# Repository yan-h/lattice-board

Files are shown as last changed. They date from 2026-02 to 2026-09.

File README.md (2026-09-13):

MIDI controller using the Wicki-Hayden layout. Heavily inspired by [Hexboard](https://shapingthesilence.com/tech/hexboard-midi-controller/), [Striso](https://www.striso.org) and [Lumatone](https://www.lumatone.io).
- 123 keys with individual LED lighting
  - 5 octaves
  - Fifthspan of 25 - i.e. each octave contains 25 notes, spanning an unbroken segment of the chain of fifths
    - Size of fifth is adjustable in firmware, providing easy access to all temperaments based on pure octaves and a chain of equal-sized perfect fifths.
- Very portable
  - 21x22x2.5cm
  - Similar in size to a small tablet, and much lighter than one.
- Tiny keys (17mm) for my tiny hands (and easier microtonal chords)
- No velocity sensitivity (or any other form of MIDI expression). This simplifies the engineering constraints by a lot, and let me design it as a very weirdly shaped mechanical keyboard.

Engineering overview
- Case and keycaps 3D-printed in PETG (Bambu Lab translucent PETG and black PETG-HF)
  - [3D models](https://cad.onshape.com/documents?nodeId=e71b068a262a341693bc0b63&resourceType=folder) made using Onshape. 
  - Printed using a Bambu Lab P1S. Keycaps were printed with the Darkmoon Satin build plate, to obtain a texture finer than a textured PEI plate, but coarser than a smooth plate.
- TTC Frozen Silent V2 Keyswitches - fully transparent, light condenser, silent.
- PCB designed in KiCad 9, manufactured with JLCPCB
- Firmware in Rust with [Embassy](https://embassy.dev/). Heavily vibecoded.
  - See [firmware/README.md](firmware/README.md) for build and flashing instructions, and the serial configuration dashboard.

Future work: [7-octave, fifthspan-50 redesign findings](docs/7x50-redesign-notes.md).




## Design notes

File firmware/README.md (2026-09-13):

# LatticeBoard firmware

Rust firmware for the RP2040, built on [Embassy](https://embassy.dev/). The board enumerates as a composite USB device with two interfaces:

- **USB-MIDI** — the actual instrument output
- **USB-CDC serial** — live logs and an interactive configuration dashboard (see below)

## Workspace layout

- `core/` — hardware-independent layout and pitch math (`layout.rs`, `pitch.rs`)
- `controller/` — the firmware binary: key scanning, LEDs, MIDI/MPE, tuning, USB

## Hardware layouts (cargo features)

Two mutually exclusive features in `controller/Cargo.toml` select the target hardware:

| Feature | Hardware | LEDs | LED data pin |
|---|---|---|---|
| `layout-prototype` (**default**) | small test board | 20 | GPIO 29 |
| `layout-5x25` | the full 123-key board | 125 | GPIO 3 |

The default is the prototype, so **building the real keyboard requires overriding the default feature** (see below).

## Prerequisites

- [rustup](https://rustup.rs) — `rust-toolchain.toml` pins Rust 1.90 and the `thumbv6m-none-eabi` target; both are installed automatically the first time you run cargo in this directory.
- [`elf2uf2-rs`](https://crates.io/crates/elf2uf2-rs) — used by the cargo runner to flash: `cargo install elf2uf2-rs`

## Build

```sh
cd firmware
cargo build --release --no-default-features --features layout-5x25   # full board
cargo build --release                                                # prototype
```

## Flash

Flashing is wired into `cargo run` via `.cargo/config.toml` — no debug probe needed, just USB:

```sh
cargo run --release --no-default-features --features layout-5x25
```

The runner script:

1. Sets the board's CDC serial port (`/dev/tty.usbmodem*`) to 1200 baud. The firmware treats a 1200-baud line coding as a "reboot into the UF2 bootloader" signal (`check_for_reset` in `controller/src/usb.rs`).
2. Waits 3 seconds for the `RPI-RP2` mass-storage bootloader to mount.
3. Runs `elf2uf2-rs -d`, which converts the ELF to UF2 and copies it to the board.

**Recovery / first flash:** if the board isn't running this firmware (so the 1200-baud trick doesn't work), hold the RP2040's BOOTSEL button while plugging in USB, then run the same `cargo run` command — the `stty` step fails harmlessly and `elf2uf2-rs` deploys as usual.

The runner script is macOS-specific (`stty -f /dev/tty.usbmodem*`); on Linux adjust to `stty -F /dev/ttyACM*`.

## Serial dashboard

Connect any terminal emulator to the CDC port (any baud rate except 1200, which triggers the bootloader reset):

```sh
screen /dev/tty.usbmodem*
```

The port starts in **log mode**, streaming `log`/defmt-style output. Press `d` to toggle the live **dashboard**, which shows brightness, hue, tuning mode, fifth size, MPE pitch-bend range, held keys, and remote MIDI voices, plus a key legend:

| Keys | Action |
|---|---|
| `[` / `]` | select previous/next of the 12 note-color anchors |
| `r`/`R`, `g`/`G`, `b`/`B` | adjust the selected anchor's RGB channels ±5 |
| `H` / `h` | shift hue offset ±1° |
| `L` / `l` | brightness ±0.05 |
| `+` / `-` | brightness ±0.02 (fine) |
| `t` | toggle tuning mode: `Standard` (12-TET MIDI notes) ↔ `Fifths` (MPE, adjustable fifth) |
| `(` / `)` | fifth size ±1 cent (clamped to 600–800¢) |
| `{` / `}` | fifth size ±0.1 cent |
| `d` | back to log mode |

Settings are in-memory only — they reset to the defaults in `controller/src/leds.rs` and `controller/src/tuning.rs` on power cycle. To persist a tweak, change the defaults there and reflash.

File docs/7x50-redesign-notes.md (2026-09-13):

# Larger keyboard: 7 octaves × fifthspan 50

Feasibility assessment saved September 12, 2026, against commit
`ee68e6a654281d804561bd37a6d07c5cd6d7d9c4`.

Status: exploratory findings only. No PCB, schematic, firmware, or mechanical
design changes have been made for this revision. The user is considering returning
to this project later; this document is the starting context for that work.

## Intent and assessment

Expand the existing Wicki-Hayden mechanical-switch MIDI keyboard from 5 octaves
and fifthspan 25 to 7 octaves and fifthspan 50. “50 notes per octave” is assumed to
mean 50 consecutive positions on the chain of fifths, following the existing
README, rather than necessarily 50 equal divisions of the octave.

This appears feasible as a medium-sized hardware revision. Existing key circuitry,
footprints, routing templates, and the RP2040 controller are useful starting
points. Expect several focused design/review sessions for a first reviewable
fabrication candidate, then manufacturing and physical bring-up, with allowance
for another PCB revision. This is a preliminary effort estimate, not a validated
schedule or a guarantee that the first manufactured board will work.

| Item | Existing board | Candidate larger board |
|---|---|---|
| Key positions | 125 nominal; 123 populated | About 350, depending on controller space |
| Scan matrix | 10 rows × 13 columns | Potentially 14 rows × 25 columns |
| Column shift registers | Two 74HC595s | Four 74HC595s, with spare outputs |
| Controller | RP2040-Zero | Likely reusable |
| Size | PCB outline about 209 × 197 mm; case about 21 × 22 cm | Roughly 40 × 28 cm at existing spacing; unverified estimate |

The proposed matrix dimensions describe electrical scanning, not a finalized
physical key arrangement. Exact fifthspan boundaries and the change from an odd
to an even fifthspan need to be worked out when generating the geometry.

## Verified baseline

- Main design: [pcb/5x25](../pcb/5x25/), KiCad 9 schematic and PCB.
- Four copper layers; the PCB includes a 5 V inner-layer zone and ground zones.
- PCB footprint inventory: 123 switches, 123 LEDs, 124 diodes, 125 capacitors,
  two 74HC595s, one RP2040-Zero, one resistor, and nine mounting holes.
- Two musical key positions are omitted for the controller.
- The controller currently uses ten row inputs, three shift-register control
  pins, and one LED data pin. Six footprint GPIO pins are unconnected.
- KiCad DRC with schematic parity checking reported zero unconnected items,
  zero schematic parity issues, and four warnings. All four warnings were
  capacitor footprints differing from their library copies: C14, C63, C88, C113.
  This establishes a useful baseline; it does not verify electrical performance.

Reproduce the baseline check from the repository root:

```sh
kicad-cli pcb drc --format json --schematic-parity \
  -o /tmp/lattice-5x25-drc.json pcb/5x25/5x25.kicad_pcb
```

On the inspected Mac, the CLI was at
`/Applications/KiCad/KiCad.app/Contents/MacOS/kicad-cli`.

## PCB and mechanical work

1. **Generate the geometry from parameters.**
   [lattice_plugins.py](../pcb/5x25/lattice_plugins.py) already clones local
   component placement and trace templates, but hardcodes 125 keys, groups of 25,
   five groups, and specific row/column/LED connections. It is a useful source of
   reusable patterns, not a complete arbitrary-size board generator. Prefer one
   authoritative layout definition that generates PCB placement and firmware
   mappings, with explicit treatment of edge keys and omitted positions.
2. **Expand the matrix and validate scanning.**
   A candidate 14×25 matrix needs 14 input pins plus three shift-register control
   pins and one LED pin: 18 GPIOs. This fits the RP2040-Zero's 20 edge GPIOs.
   Four cascaded 8-bit 595s provide enough column outputs. Pin assignment,
   initialization, scan timing, and long interconnect behavior still need review.
3. **Establish an LED power budget.**
   At comparable lighting settings, LED load scales to approximately 2.8 times
   the current board. Measure or verify the actual LED current, decide maximum
   brightness, then design the supply path, copper distribution, decoupling,
   input protection, and logic-level interface accordingly. USB-only power versus
   a separate supply remains undecided.
4. **Update the enclosure and mounting scheme.**
   The much wider PCB needs appropriate mechanical support. Compare a single
   PCB with connected sections if fabrication or enclosure constraints justify
   that complexity. Local mechanical files in [models](../models/) are STEP/3MF
   exports; the README links the original Onshape models. The editable Onshape
   design was not inspected in this assessment.

Hardware references checked during the assessment:
[Waveshare RP2040-Zero documentation](https://www.waveshare.com/wiki/RP2040-Zero)
and [TI SN74HC595 documentation](https://www.ti.com/product/SN74HC595).

## Firmware findings to carry forward

- **LED indices must be widened.**
  [layout_5x25.rs](../firmware/controller/src/layouts/layout_5x25.rs) uses `u8`
  entries and reserves `255` for `NO_LED`; indices for 350 LEDs cannot fit.
  The generic reverse-lookup helper in
  [core/layout.rs](../firmware/core/src/layout.rs) also accepts `u8` entries.
  Use a wider representation and an unambiguous missing-entry value.
- **Unify LED counts.** The layout declares 123 LEDs, while
  [leds.rs](../firmware/controller/src/leds.rs) sends a 125-LED buffer.
- **Add a layout and update row pin assignments.** The scanner in
  [keys/shift_reg.rs](../firmware/controller/src/keys/shift_reg.rs) loops over
  layout constants, but the current row-pin macro names exactly ten pins.
  RAM for a few hundred keys and LEDs appears modest; actual scan latency and
  CPU load have not been benchmarked.
- **Review LED refresh cost.** At an assumed 800 kHz, transmitting 350 RGB LEDs
  takes about 10.5 ms before reset time, while the task requests a 2 ms tick.
  Lighting also repeatedly searches the board for pitches per active voice.
  Choose a realistic refresh rate and consider cached or change-driven updates.
- **Review event bursts and held-key capacities.** The scanner drops events if
  its 32-entry MIDI queue is full, potentially losing note-offs. Local held-key
  visualization has a 16-entry capacity; other voice/highlight collections have
  32-entry limits. More total keys do not inherently require more polyphony, but
  the intended simultaneous-key behavior and debounce should be checked.
- **Preserve the distinction between MIDI modes.** In the inspected
  [tuning.rs](../firmware/controller/src/tuning.rs), `Fifths` is the default and
  encodes octave/fifth offsets as channel/note numbers, clamped to 16 channels
  and 128 notes. Validate the new layout center and all edge coordinates to avoid
  clamping aliases. `Standard` with a non-700-cent fifth uses the MPE allocator,
  which has 15 note channels; that limit is simultaneous bent voices, not total
  keyboard keys. Do not assume the README fully describes current behavior.

## Suggested restart point

First generate a reviewable 7×50 physical key layout and board outline, preserving
the existing switch/keycap geometry. Confirm the exact fifthspan, musical range,
controller location, hand reach, and desk footprint before detailed routing.

Then settle power and single-board versus sectional construction; produce the
schematic, placement, routing, mounting, and firmware mappings from the agreed
layout. Verify mapping uniqueness and coverage, DRC/ERC and schematic parity,
firmware builds, and power/mechanical assumptions before preparing fabrication
files. Physical bring-up should exercise every key and LED, simultaneous presses,
release-event reliability, scan latency, and voltage drop at maximum permitted
brightness.

No budget, power architecture, sectional construction, or exact outline has been
approved yet. Do not treat the candidate dimensions or scan matrix as final design
requirements.

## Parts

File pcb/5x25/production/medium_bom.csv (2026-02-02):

Designator | Footprint | Quantity | Value | LCSC Part #
C10, C100, C101, C102, C103, C104, C105, C106, C107, C108, C109, C11, C110, C111, C112, C113, C114, C115, C116, C117, C118, C119, C12, C120, C121, C122, C123, C124, C125, C14, C15, C16, C17, C18, C19, C2, C20, C21, C22, C23, C24, C25, C26, C27, C28, C29, C3, C30, C31, C32, C33, C34, C35, C36, C37, C38, C39, C4, C40, C41, C42, C43, C44, C45, C46, C47, C48, C49, C5, C50, C51, C52, C53, C54, C55, C56, C57, C58, C59, C6, C60, C61, C62, C63, C64, C65, C66, C67, C68, C69, C7, C70, C71, C72, C73, C74, C75, C76, C77, C78, C79, C8, C80, C81, C82, C83, C84, C85, C86, C87, C88, C89, C9, C90, C900, C901, C91, C92, C93, C94, C95, C96, C97, C98, C99 | 0603 | 125 | 100nF
D10, D100, D101, D102, D103, D104, D105, D106, D107, D108, D109, D11, D110, D111, D112, D113, D114, D115, D116, D117, D118, D119, D12, D120, D121, D122, D123, D124, D125, D14, D15, D16, D17, D18, D19, D2, D20, D21, D22, D23, D24, D25, D26, D27, D28, D29, D3, D30, D31, D32, D33, D34, D35, D36, D37, D38, D39, D4, D40, D41, D42, D43, D44, D45, D46, D47, D48, D49, D5, D50, D51, D52, D53, D54, D55, D56, D57, D58, D59, D6, D60, D61, D62, D63, D64, D65, D66, D67, D68, D69, D7, D70, D71, D72, D73, D74, D75, D76, D77, D78, D79, D8, D80, D81, D82, D83, D84, D85, D86, D87, D88, D89, D9, D90, D900, D91, D92, D93, D94, D95, D96, D97, D98, D99 | D_SOD-323F | 124 | 1N4148WS
LED10, LED100, LED101, LED102, LED103, LED104, LED105, LED106, LED107, LED108, LED109, LED11, LED110, LED111, LED112, LED113, LED114, LED115, LED116, LED117, LED118, LED119, LED12, LED120, LED121, LED122, LED123, LED124, LED125, LED14, LED15, LED16, LED17, LED18, LED19, LED2, LED20, LED21, LED22, LED23, LED24, LED25, LED26, LED27, LED28, LED29, LED3, LED30, LED31, LED32, LED33, LED34, LED35, LED36, LED37, LED38, LED39, LED4, LED40, LED41, LED42, LED43, LED44, LED45, LED46, LED47, LED48, LED49, LED5, LED50, LED51, LED52, LED53, LED54, LED55, LED56, LED57, LED58, LED59, LED6, LED60, LED61, LED62, LED63, LED64, LED65, LED66, LED67, LED68, LED69, LED7, LED70, LED71, LED72, LED73, LED74, LED75, LED76, LED77, LED78, LED79, LED8, LED80, LED81, LED82, LED83, LED84, LED85, LED86, LED87, LED88, LED89, LED9, LED90, LED91, LED92, LED93, LED94, LED95, LED96, LED97, LED98, LED99 | SK6803-MINI-E | 123 | SK6803-MINI-E
R1 | 0402 | 1 | 220R
RZ1 | RP2040-Zero | 1 | RP2040-Zero
SW10, SW100, SW101, SW102, SW103, SW104, SW105, SW106, SW107, SW108, SW109, SW11, SW110, SW111, SW112, SW113, SW114, SW115, SW116, SW117, SW118, SW119, SW12, SW120, SW121, SW122, SW123, SW124, SW125, SW14, SW15, SW16, SW17, SW18, SW19, SW2, SW20, SW21, SW22, SW23, SW24, SW25, SW26, SW27, SW28, SW29, SW3, SW30, SW31, SW32, SW33, SW34, SW35, SW36, SW37, SW38, SW39, SW4, SW40, SW41, SW42, SW43, SW44, SW45, SW46, SW47, SW48, SW49, SW5, SW50, SW51, SW52, SW53, SW54, SW55, SW56, SW57, SW58, SW59, SW6, SW60, SW61, SW62, SW63, SW64, SW65, SW66, SW67, SW68, SW69, SW7, SW70, SW71, SW72, SW73, SW74, SW75, SW76, SW77, SW78, SW79, SW8, SW80, SW81, SW82, SW83, SW84, SW85, SW86, SW87, SW88, SW89, SW9, SW90, SW91, SW92, SW93, SW94, SW95, SW96, SW97, SW98, SW99 | SW_MX_17 | 123 | MX_Switch
U1, U2 | TSSOP-16 | 2 | 74HC595

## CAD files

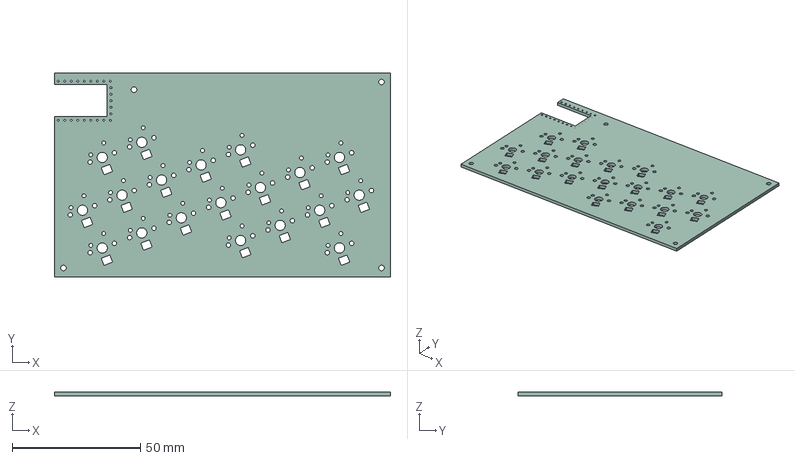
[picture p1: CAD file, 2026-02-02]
models/boards/prototype.step
131.0 x 79.5 x 1.51 mm

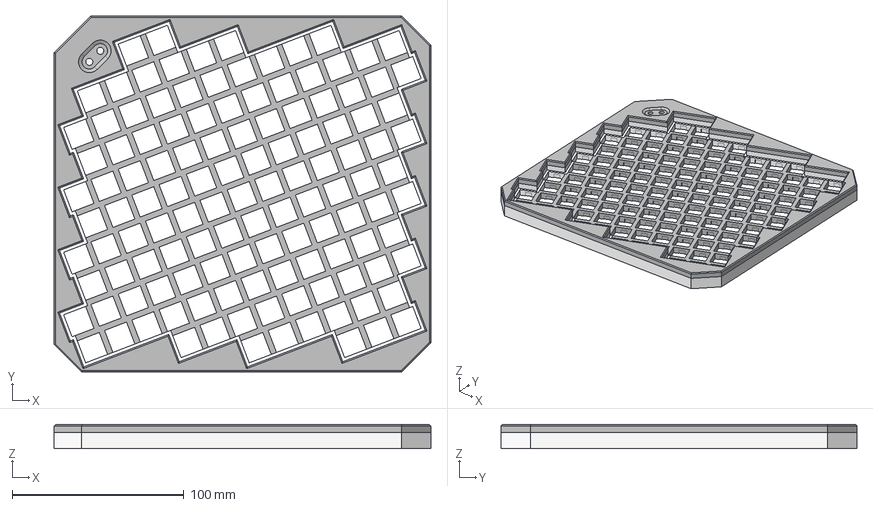
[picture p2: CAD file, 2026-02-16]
models/cases/5x25/top.step
219.4 x 207.4 x 14.0 mm

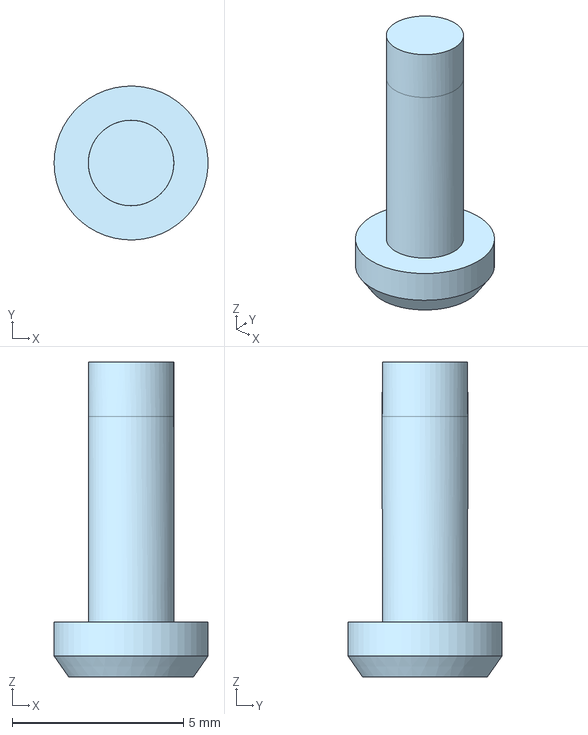
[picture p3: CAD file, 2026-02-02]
models/cases/prototype/button_rod.step
4.50 x 4.50 x 9.21 mm

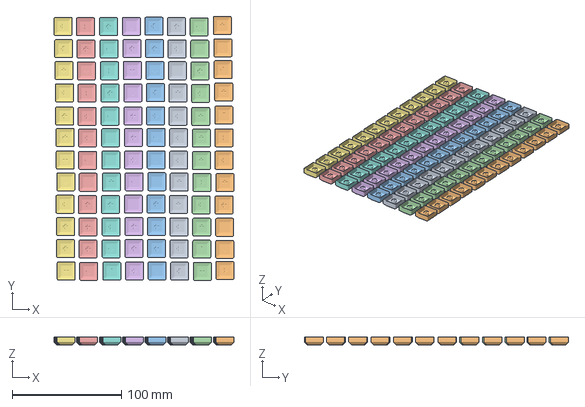
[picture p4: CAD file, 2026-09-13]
models/keycaps/17mm_keycaps.3mf
164.7 x 241.6 x 7.40 mm
key_a0.step x 48
key_a1.step x 48

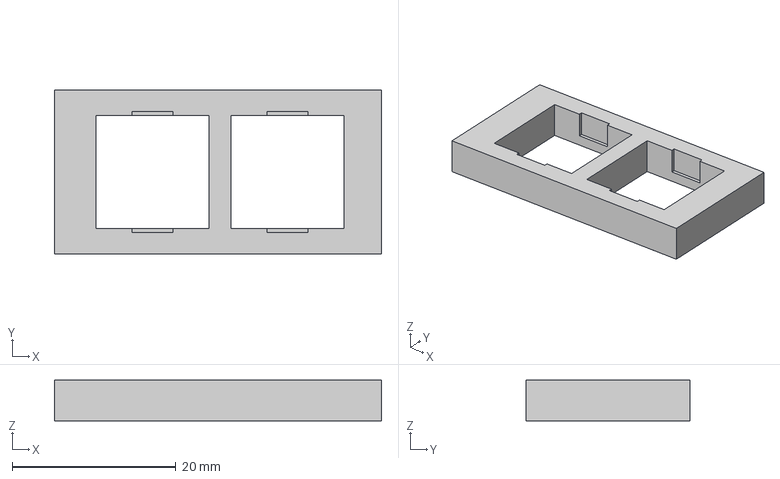
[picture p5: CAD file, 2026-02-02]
models/utils/TestPair.step
40.0 x 20.0 x 5.00 mm

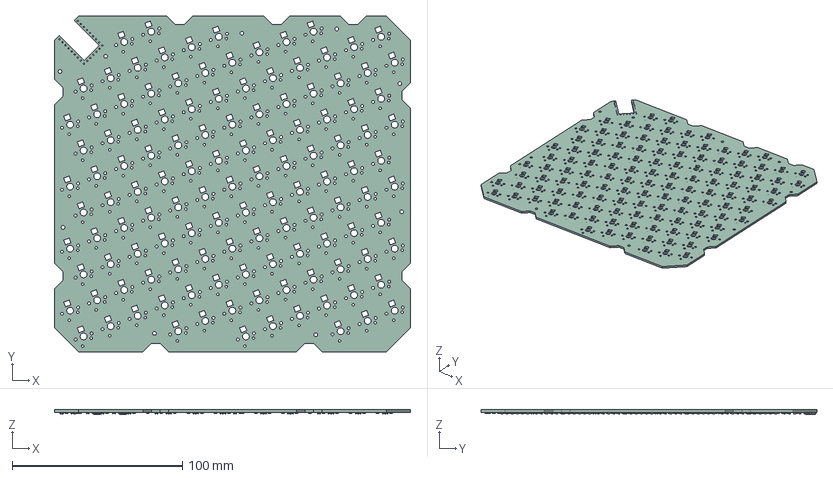
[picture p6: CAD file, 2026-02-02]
pcb/5x25/5x25.step
209.0 x 197.0 x 2.70 mm
D_SOD-323F x 124
C_0603_1608Metric x 125
TSSOP-16_4.4x5mm_P0.65mm x 2
R_0402_1005Metric
medium_PCB

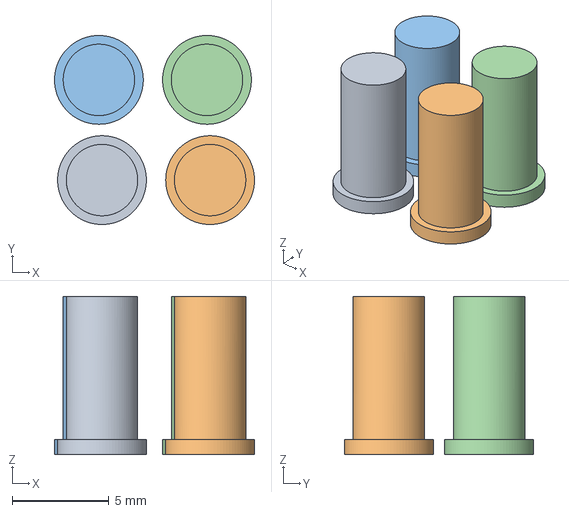
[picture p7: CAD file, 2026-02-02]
models/cases/5x25/button_rods.3mf
10.4 x 9.79 x 8.21 mm
5x25_Case - Boot Button Rod-2.step x 4

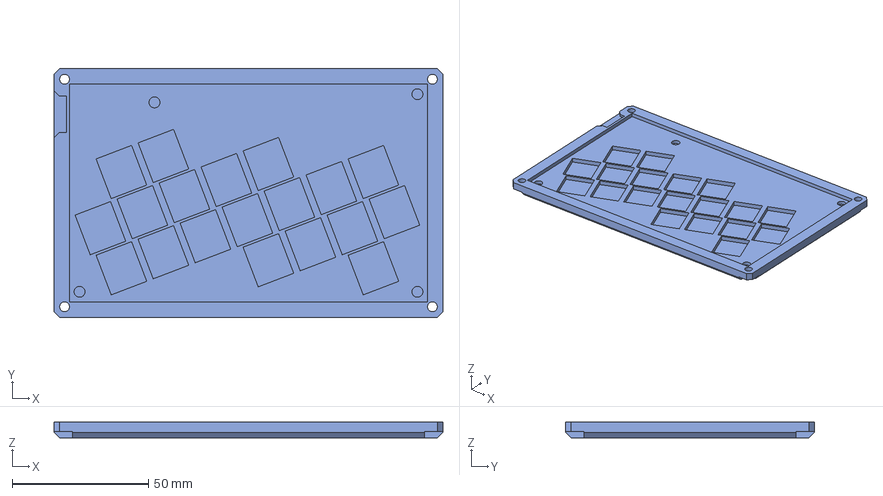
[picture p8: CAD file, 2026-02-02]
models/cases/prototype/bottom.step
142.8 x 91.3 x 5.80 mm

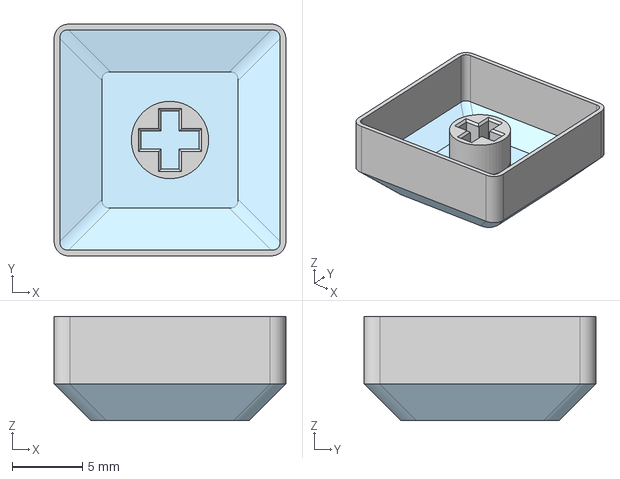
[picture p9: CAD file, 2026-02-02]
models/keycaps/17mm_key0.step
16.5 x 16.5 x 7.40 mm

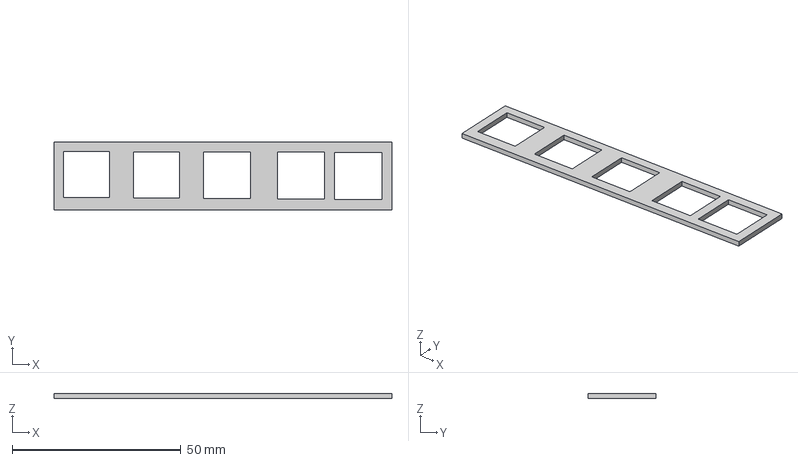
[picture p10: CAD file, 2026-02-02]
models/utils/SwitchFitTester.step
100.0 x 20.0 x 1.50 mm

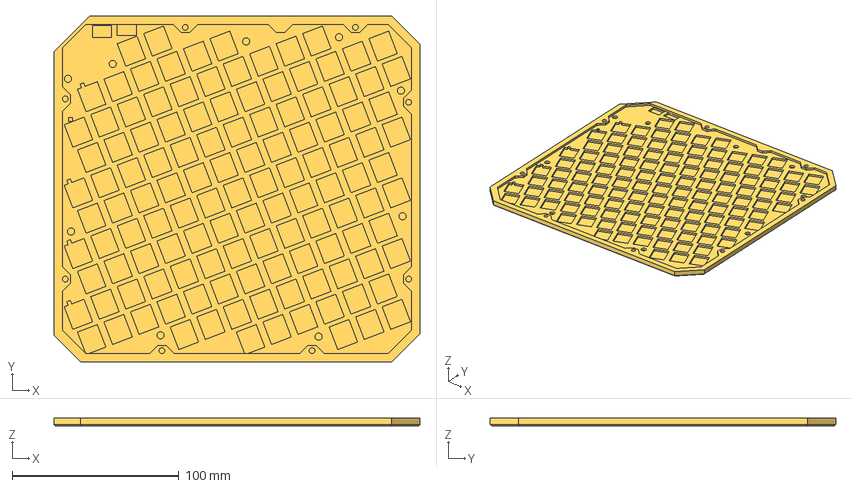
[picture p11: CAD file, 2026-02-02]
models/cases/5x25/bottom.step
219.4 x 207.4 x 4.60 mm

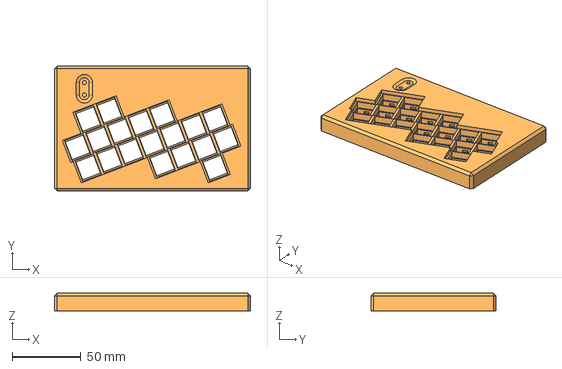
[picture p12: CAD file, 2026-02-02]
models/cases/prototype/Top.step
142.8 x 91.3 x 13.0 mm

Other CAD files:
models/keycaps/17mm_key1.step
models/utils/SingleSwitch.step
models/cases/5x25/bottom.3mf
models/cases/5x25/top.3mf

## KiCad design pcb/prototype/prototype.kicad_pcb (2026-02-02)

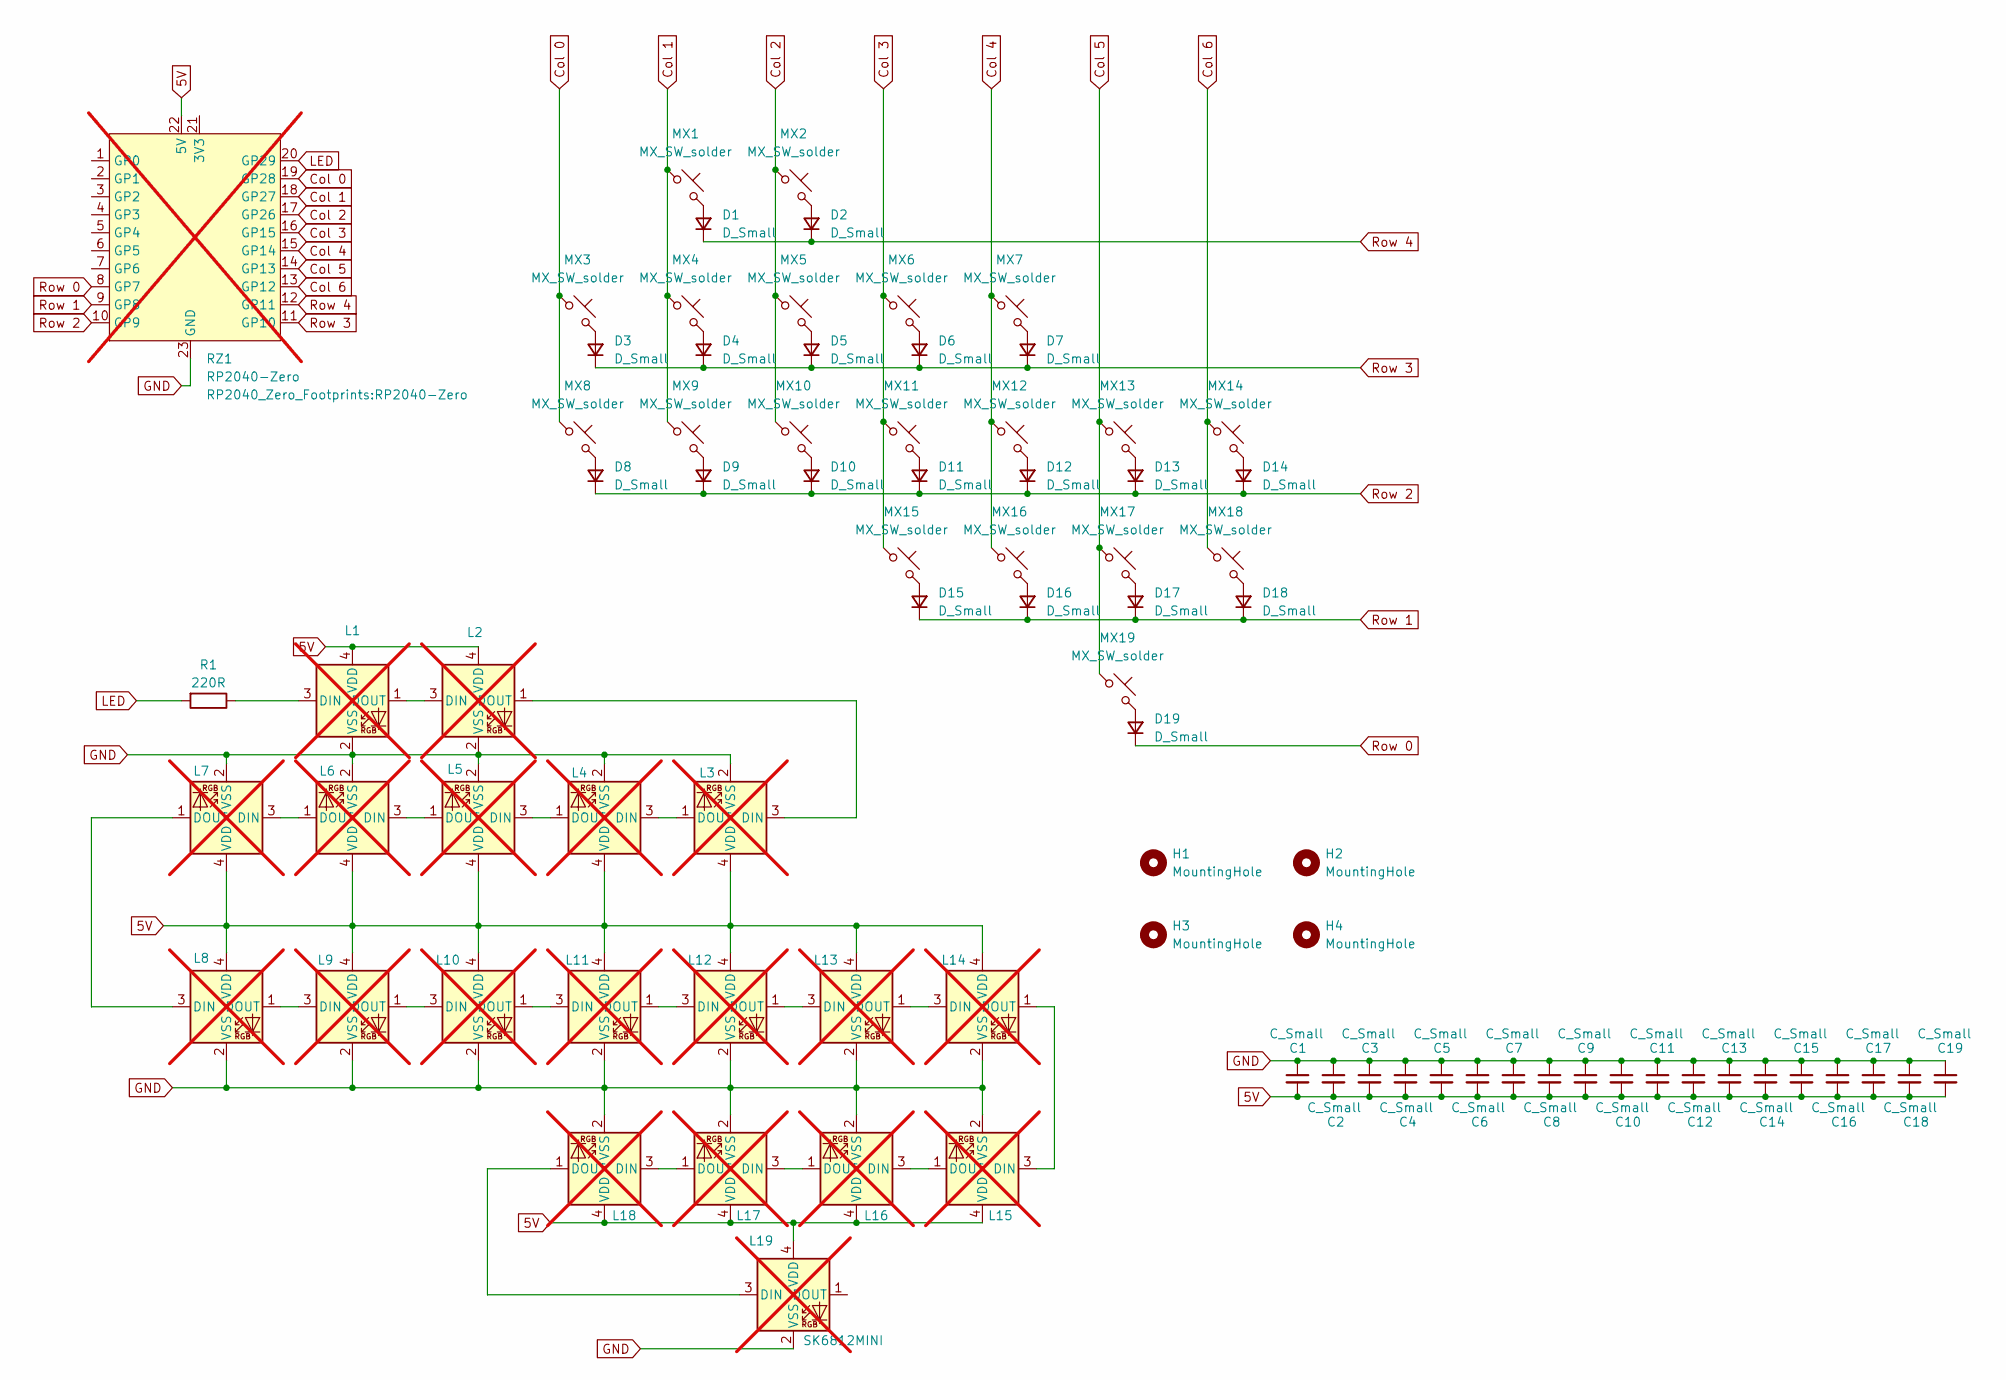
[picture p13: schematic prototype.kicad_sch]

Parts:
C1, C2, C3, C4, C5, C6, C7, C8, C9, C10, C11, C12, C13, C14, C15, C16, C17, C18, C19: C_Small; C_0603_1608Metric
D1, D2, D3, D4, D5, D6, D7, D8, D9, D10, D11, D12, D13, D14, D15, D16, D17, D18, D19: D_Small; D_SOD-323F
H1, H2, H3, H4: MountingHole; MountingHole_2.2mm_M2_Pad
L1, L2, L3, L4, L5, L6, L7, L8, L9, L10, L11, L12, L13, L14, L15, L16, L17, L18, L19: SK6812MINI; SK6812-MINI-E; not fitted
MX1, MX2, MX3, MX4, MX5, MX6, MX7, MX8, MX9, MX10, MX11, MX12, MX13, MX14, MX15, MX16, MX17, MX18, MX19: MX_SW_solder; SW_MX_16
R1: 220R; R_0402_1005Metric
RZ1: RP2040-Zero; not fitted

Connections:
5V: C1.2, C2.2, C3.2, C4.2, C5.2, C6.2, C7.2, C8.2, C9.2, C10.2, C11.2, C12.2, C13.2, C14.2, C15.2, C16.2, C17.2, C18.2, C19.2, L1.4 (VDD), L2.4 (VDD), L3.4 (VDD), L4.4 (VDD), L5.4 (VDD), L6.4 (VDD), L7.4 (VDD), L8.4 (VDD), L9.4 (VDD), L10.4 (VDD), L11.4 (VDD), L12.4 (VDD), L13.4 (VDD), L14.4 (VDD), L15.4 (VDD), L16.4 (VDD), L17.4 (VDD), L18.4 (VDD), L19.4 (VDD), RZ1.22 (5V)
Col 0: MX3.1, MX8.1, RZ1.19 (GP28)
Col 1: MX1.1, MX4.1, MX9.1, RZ1.18 (GP27)
Col 2: MX2.1, MX5.1, MX10.1, RZ1.17 (GP26)
Col 3: MX6.1, MX11.1, MX15.1, RZ1.16 (GP15)
Col 4: MX7.1, MX12.1, MX16.1, RZ1.15 (GP14)
Col 5: MX13.1, MX17.1, MX19.1, RZ1.14 (GP13)
Col 6: MX14.1, MX18.1, RZ1.13 (GP12)
GND: C1.1, C2.1, C3.1, C4.1, C5.1, C6.1, C7.1, C8.1, C9.1, C10.1, C11.1, C12.1, C13.1, C14.1, C15.1, C16.1, C17.1, C18.1, C19.1, L1.2 (VSS), L2.2 (VSS), L3.2 (VSS), L4.2 (VSS), L5.2 (VSS), L6.2 (VSS), L7.2 (VSS), L8.2 (VSS), L9.2 (VSS), L10.2 (VSS), L11.2 (VSS), L12.2 (VSS), L13.2 (VSS), L14.2 (VSS), L15.2 (VSS), L16.2 (VSS), L17.2 (VSS), L18.2 (VSS), L19.2 (VSS), RZ1.23 (GND)
LED: R1.2, RZ1.20 (GP29)
unnamed: D1.2 (A), MX1.2
unnamed: D2.2 (A), MX2.2
unnamed: D3.2 (A), MX3.2
unnamed: D4.2 (A), MX4.2
unnamed: D5.2 (A), MX5.2
unnamed: D6.2 (A), MX6.2
unnamed: D7.2 (A), MX7.2
unnamed: D8.2 (A), MX8.2
unnamed: D9.2 (A), MX9.2
unnamed: D10.2 (A), MX10.2
unnamed: D11.2 (A), MX11.2
unnamed: D12.2 (A), MX12.2
unnamed: D13.2 (A), MX13.2
unnamed: D14.2 (A), MX14.2
unnamed: D15.2 (A), MX15.2
unnamed: D16.2 (A), MX16.2
unnamed: D17.2 (A), MX17.2
unnamed: D18.2 (A), MX18.2
unnamed: D19.2 (A), MX19.2
unnamed: L1.3 (DIN), R1.1
unnamed: L1.1 (DOUT), L2.3 (DIN)
unnamed: L2.1 (DOUT), L3.3 (DIN)
unnamed: L3.1 (DOUT), L4.3 (DIN)
unnamed: L4.1 (DOUT), L5.3 (DIN)
unnamed: L5.1 (DOUT), L6.3 (DIN)
unnamed: L6.1 (DOUT), L7.3 (DIN)
unnamed: L7.1 (DOUT), L8.3 (DIN)
unnamed: L8.1 (DOUT), L9.3 (DIN)
unnamed: L9.1 (DOUT), L10.3 (DIN)
unnamed: L10.1 (DOUT), L11.3 (DIN)
unnamed: L11.1 (DOUT), L12.3 (DIN)
unnamed: L12.1 (DOUT), L13.3 (DIN)
unnamed: L13.1 (DOUT), L14.3 (DIN)
unnamed: L14.1 (DOUT), L15.3 (DIN)
unnamed: L15.1 (DOUT), L16.3 (DIN)
unnamed: L16.1 (DOUT), L17.3 (DIN)
unnamed: L17.1 (DOUT), L18.3 (DIN)
unnamed: L18.1 (DOUT), L19.3 (DIN)
Row 0: D19.1 (K), RZ1.8 (GP7)
Row 1: D15.1 (K), D16.1 (K), D17.1 (K), D18.1 (K), RZ1.9 (GP8)
Row 2: D8.1 (K), D9.1 (K), D10.1 (K), D11.1 (K), D12.1 (K), D13.1 (K), D14.1 (K), RZ1.10 (GP9)
Row 3: D3.1 (K), D4.1 (K), D5.1 (K), D6.1 (K), D7.1 (K), RZ1.11 (GP10)
Row 4: D1.1 (K), D2.1 (K), RZ1.12 (GP11)

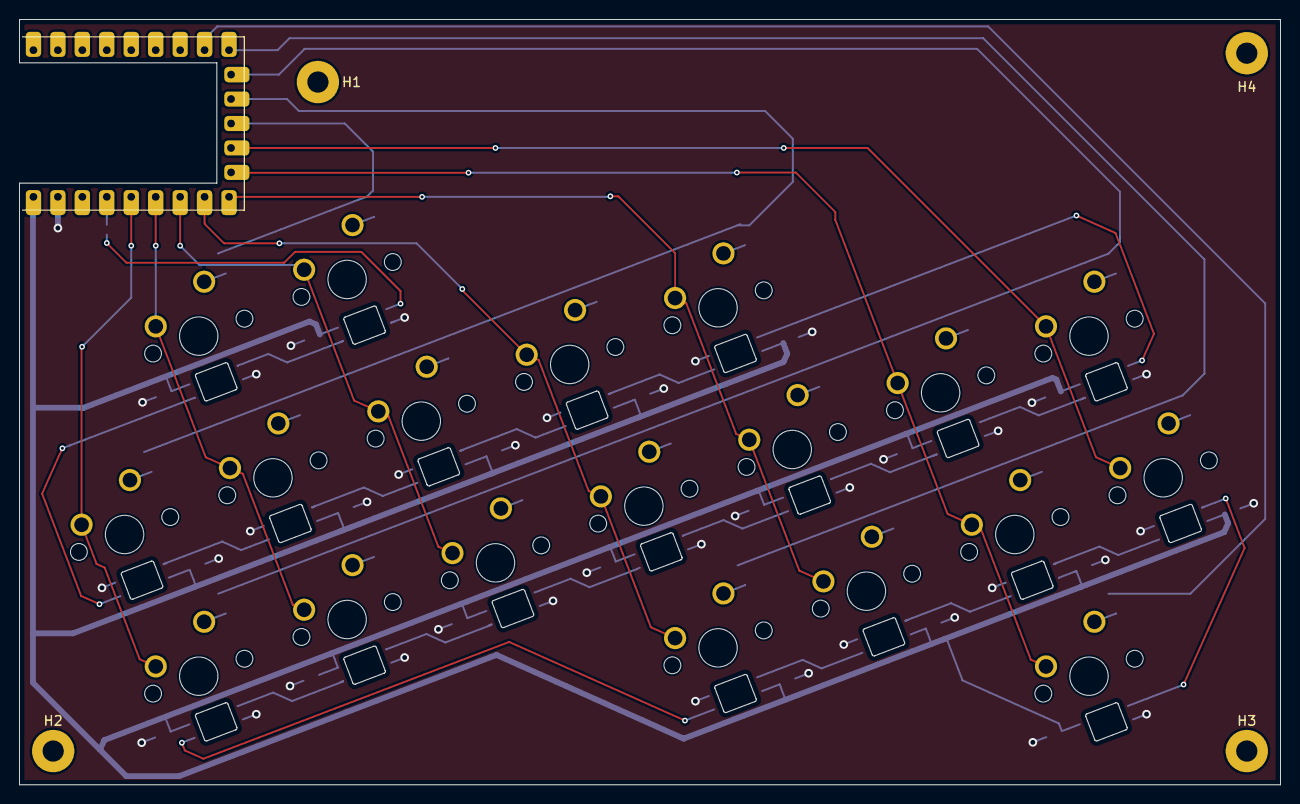
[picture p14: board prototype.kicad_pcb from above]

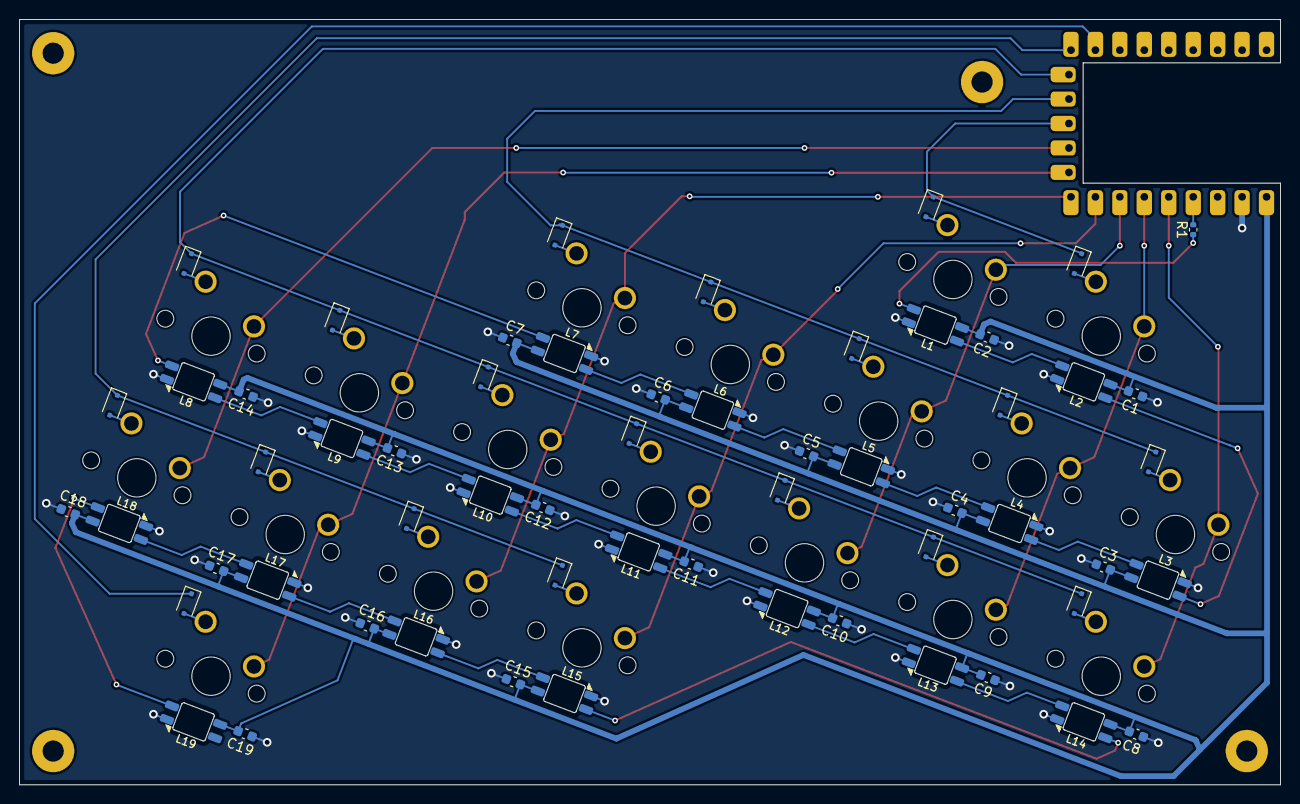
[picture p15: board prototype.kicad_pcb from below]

Board: 2 copper layers, 131.0 x 79.5 mm, 82 parts (58 on the bottom side), 53 nets.

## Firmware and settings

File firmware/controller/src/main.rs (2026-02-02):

#![no_std]
#![no_main]

use defmt_rtt as _;
use embassy_executor::Spawner;
use embassy_rp::bind_interrupts;
use embassy_rp::peripherals::{PIO0, USB};
use embassy_rp::pio::Pio;
use embassy_rp::usb::{Driver, InterruptHandler};
use embassy_time::{Duration, Timer};
use embassy_usb::class::cdc_acm::{CdcAcmClass, State};
use embassy_usb::class::midi::MidiClass;
use embassy_usb::{Builder, Config};
use log::info;
use panic_probe as _;
use static_cell::StaticCell;

mod keys;
mod layouts;
mod leds;
mod logging;
mod midi;
mod mpe;
mod tuning;
mod usb;
mod util;

pub use lattice_board_core::layout;
pub use lattice_board_core::pitch;

bind_interrupts!(struct Irqs {
    USBCTRL_IRQ => InterruptHandler<USB>;
    PIO0_IRQ_0 => embassy_rp::pio::InterruptHandler<PIO0>;
});

#[embassy_executor::main]
async fn main(spawner: Spawner) {
    let p = embassy_rp::init(Default::default());

    let driver = Driver::new(p.USB, Irqs);

    let mut config = Config::new(0x2E8A, 0x000a);
    config.manufacturer = Some("YH");
    config.product = Some("LatticeBoard");

    let uid = util::read_unique_id(p.FLASH);
    static SERIAL_STRING: StaticCell<heapless::String<32>> = StaticCell::new();
    let uid_static = SERIAL_STRING.init(uid);
    config.serial_number = Some(uid_static.as_str());

    static CONFIG_DESCRIPTOR: StaticCell<[u8; 256]> = StaticCell::new();
    static BOS_DESCRIPTOR: StaticCell<[u8; 256]> = StaticCell::new();
    static CONTROL_BUF: StaticCell<[u8; 64]> = StaticCell::new();
    static STATE: StaticCell<State> = StaticCell::new();

    let mut builder = Builder::new(
        driver,
        config,
        CONFIG_DESCRIPTOR.init([0; 256]),
        BOS_DESCRIPTOR.init([0; 256]),
        &mut [],
        CONTROL_BUF.init([0; 64]),
    );

    let class_cdc = CdcAcmClass::new(&mut builder, STATE.init(State::new()), 64);
    let class_midi = MidiClass::new(&mut builder, 1, 1, 64);

    let usb = builder.build();

    logging::init();
    let pio = Pio::new(p.PIO0, Irqs);

    #[cfg(feature = "layout-5x25")]
    {
        spawner
            .spawn(leds::led_task(pio, p.PIN_3, p.DMA_CH0))
            .unwrap();
    }
    #[cfg(feature = "layout-prototype")]
    {
        spawner
            .spawn(leds::led_task(pio, p.PIN_29, p.DMA_CH0))
            .unwrap();
    }

    spawner.spawn(usb::usb_task(usb)).unwrap();
    spawner.spawn(usb::serial_task(class_cdc)).unwrap();

    static MIDI_CHANNEL: StaticCell<
        embassy_sync::channel::Channel<
            embassy_sync::blocking_mutex::raw::CriticalSectionRawMutex,
            midi::MidiEvent,
            32,
        >,
    > = StaticCell::new();
    let channel = MIDI_CHANNEL.init(embassy_sync::channel::Channel::new());

    spawner
        .spawn(midi::midi_task(class_midi, channel.receiver()))
        .unwrap();

    use crate::get_rows;

    #[cfg(feature = "layout-5x25")]
    {
        Timer::after(Duration::from_millis(2000)).await;
        crate::layouts::log_key_map();

        let row_pins = get_rows!(p);
        let data_pin = p.PIN_0.into();
        let latch_pin = p.PIN_1.into();
        let clock_pin = p.PIN_2.into();

        spawner
            .spawn(keys::keys_task_shift_reg(
                row_pins,
                data_pin,
                latch_pin,
                clock_pin,
                channel.sender(),
            ))
            .unwrap();
    }

    #[cfg(feature = "layout-prototype")]
    {
        use crate::get_cols;
        let row_pins = get_rows!(p);
        let col_pins = get_cols!(p);
        spawner
            .spawn(keys::keys_task_direct(row_pins, col_pins, channel.sender()))
            .unwrap();
    }

    info!("Controller start. Serial number: {}", uid_static.as_str());

    loop {
        Timer::after(Duration::from_secs(1)).await;
    }
}

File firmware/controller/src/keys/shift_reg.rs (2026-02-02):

use embassy_executor::task;
use embassy_rp::gpio::{AnyPin, Input, Pull};
use embassy_time::{Duration, Timer};
use log::info;

use crate::layout::Layout;
use crate::layouts::{CurrentLayout, COLS, ROWS};
use core::cell::RefCell;
use embassy_sync::blocking_mutex::raw::CriticalSectionRawMutex;
use embassy_sync::blocking_mutex::Mutex;
use heapless::Vec;
use lattice_board_core::layout::Coordinate;

// Shared state for Active Keys (Coordinates)
pub static ACTIVE_KEYS: Mutex<CriticalSectionRawMutex, RefCell<Vec<Coordinate, 16>>> =
    Mutex::new(RefCell::new(Vec::new()));

#[task]
pub async fn keys_task_shift_reg(
    row_pins: [AnyPin; ROWS],
    // Shift Register Pins
    data_pin: AnyPin,  // GPIO 0
    latch_pin: AnyPin, // GPIO 1
    clock_pin: AnyPin, // GPIO 2
    sender: embassy_sync::channel::Sender<
        'static,
        embassy_sync::blocking_mutex::raw::CriticalSectionRawMutex,
        crate::midi::MidiEvent,
        32,
    >,
) {
    use embassy_rp::gpio::{Level, Output};

    // Active High Configuration (Standard 74HC595 + Rows with Pull-Down)
    // Shift in '1', Rows read High when pressed.
    let rows: [Input<'static>; ROWS] = row_pins.map(|p| Input::new(p, Pull::Down));

    let mut data = Output::new(data_pin, Level::Low);
    let mut latch = Output::new(latch_pin, Level::Low);
    let mut clock = Output::new(clock_pin, Level::Low);

    info!("Keys task started. Shift Register Scanning (Active High).");

    let mut key_state = [[false; COLS]; ROWS];

    loop {
        // Ensure we start clean
        data.set_low();
        latch.set_low();
        clock.set_low();

        // ---------------------------------------------------------
        // Column 0: Shift in a High bit
        // ---------------------------------------------------------

        // 1. Set Data High
        data.set_high();

        // 2. Pulse Clock to shift '1' into Q0
        clock.set_high();
        Timer::after(Duration::from_micros(1)).await;
        clock.set_low();
        Timer::after(Duration::from_micros(1)).await;

        // 3. Pulse Latch to output
        latch.set_high();
        Timer::after(Duration::from_micros(1)).await;
        latch.set_low();
        Timer::after(Duration::from_micros(1)).await;

        scan_rows(0, &rows, &mut key_state, &sender).await;

        // ---------------------------------------------------------
        // Columns 1..COLS: Shift in Low bits (pushing the High bit along)
        // ---------------------------------------------------------
        data.set_low(); // We want 0s following the single 1

        for c_idx in 1..COLS {
            // Pulse Clock to shift
            clock.set_high();
            Timer::after(Duration::from_micros(1)).await;
            clock.set_low();
            Timer::after(Duration::from_micros(1)).await;

            // Pulse Latch to output
            latch.set_high();
            Timer::after(Duration::from_micros(1)).await;
            latch.set_low();
            Timer::after(Duration::from_micros(1)).await;

            scan_rows(c_idx, &rows, &mut key_state, &sender).await;
        }

        // Scan rate control: Fast as possible while yielding
        Timer::after(Duration::from_micros(100)).await;
    }
}

// Helper to scan rows and update state
async fn scan_rows(
    c_idx: usize,
    rows: &[Input<'static>; ROWS],
    key_state: &mut [[bool; COLS]; ROWS],
    sender: &embassy_sync::channel::Sender<
        'static,
        embassy_sync::blocking_mutex::raw::CriticalSectionRawMutex,
        crate::midi::MidiEvent,
        32,
    >,
) {
    use crate::midi::ToU7;
    use log::error;

    for (r_idx, row) in rows.iter().enumerate() {
        let is_pressed = row.is_high();
        let was_pressed = key_state[r_idx][c_idx];

        if is_pressed != was_pressed {
            key_state[r_idx][c_idx] = is_pressed;

            // Debug: Raw Matrix Event (Optional, good for verification)
            if is_pressed {
                //info!("Raw Press: r{} c{}", r_idx, c_idx);
            }

            // State Changed
            // State Changed
            if let Some(coord) = CurrentLayout::key_to_coord(r_idx, c_idx) {
                // info!("Coord: {:?}", coord);

                if let Some(event) =
                    crate::tuning::get_midi_event::<CurrentLayout>(coord, 100.to_u7(), is_pressed)
                {
                    if let Err(_) = sender.try_send(event) {
                        error!("MIDI Channel Full! Dropping Event");
                    }

                    // Track Active keys
                    ACTIVE_KEYS.lock(|c| {
                        let mut keys = c.borrow_mut();
                        if is_pressed {
                            if !keys.contains(&coord) {
                                let _ = keys.push(coord);
                            }
                        } else {
                            keys.retain(|&x| x != coord);
                        }
                    });
                }
            }
        }
    }
}

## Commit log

2026-02-16 Fix misshapen wall in models
    [bottom.3mf, top.3mf, top.step]
2026-07-17 Raise default LED brightness and polish serial dashboard
    - Default brightness 0.05 -> 0.14
    - Fine brightness step (+/-) 0.01 -> 0.02
    - Remove MPE pitch-bend-range shortcuts (,.<>)
    - Add shortcut legend to the dashboard view
2026-07-17 Update 5x25 top case and 17mm keycap models
    [17mm_keycaps.3mf, top.3mf]
